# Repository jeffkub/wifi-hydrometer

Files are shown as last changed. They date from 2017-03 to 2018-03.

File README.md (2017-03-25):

# wifi-hydrometer
A WiFi-enabled hydrometer and temperature sensor using a ESP8266.  Concept taken from [iSpindel](https://github.com/universam1/iSpindel) and miniturized to fit inside a standard size soda bottle perform.
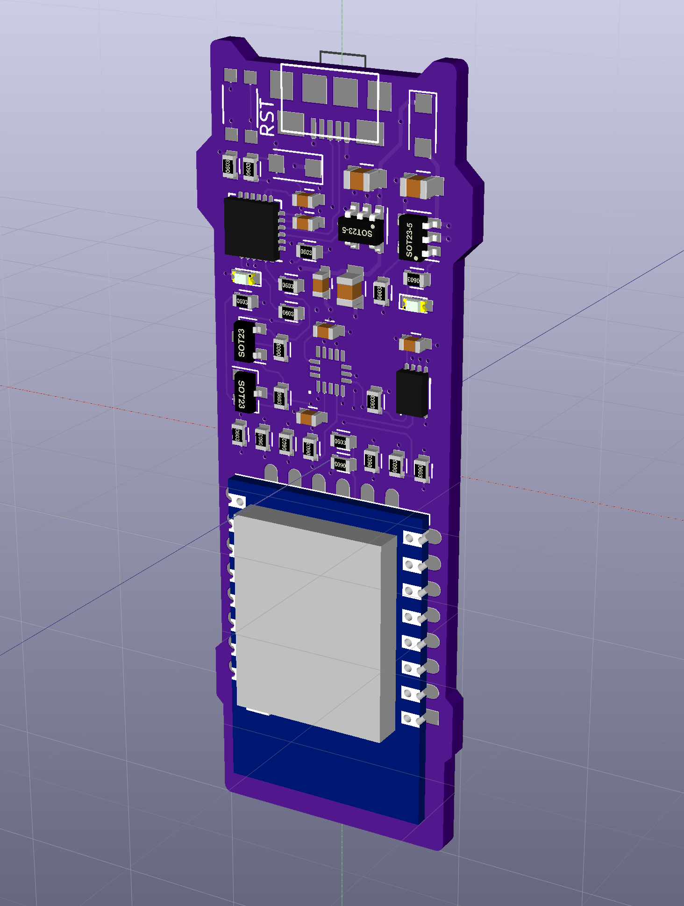
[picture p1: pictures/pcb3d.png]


# Licensing
Design is based on the Adafruit Feather ESP8266 HUZZAH.  
For more details, check out the product page at

  * https://www.adafruit.com/product/2821

Adafruit invests time and resources providing this open source design, 
please support Adafruit and open-source hardware by purchasing 
products from Adafruit!

Adapted from a design by Adafruit Industries.  
Creative Commons Attribution, Share-Alike license, check license.txt for more information
All text above must be included in any redistribution

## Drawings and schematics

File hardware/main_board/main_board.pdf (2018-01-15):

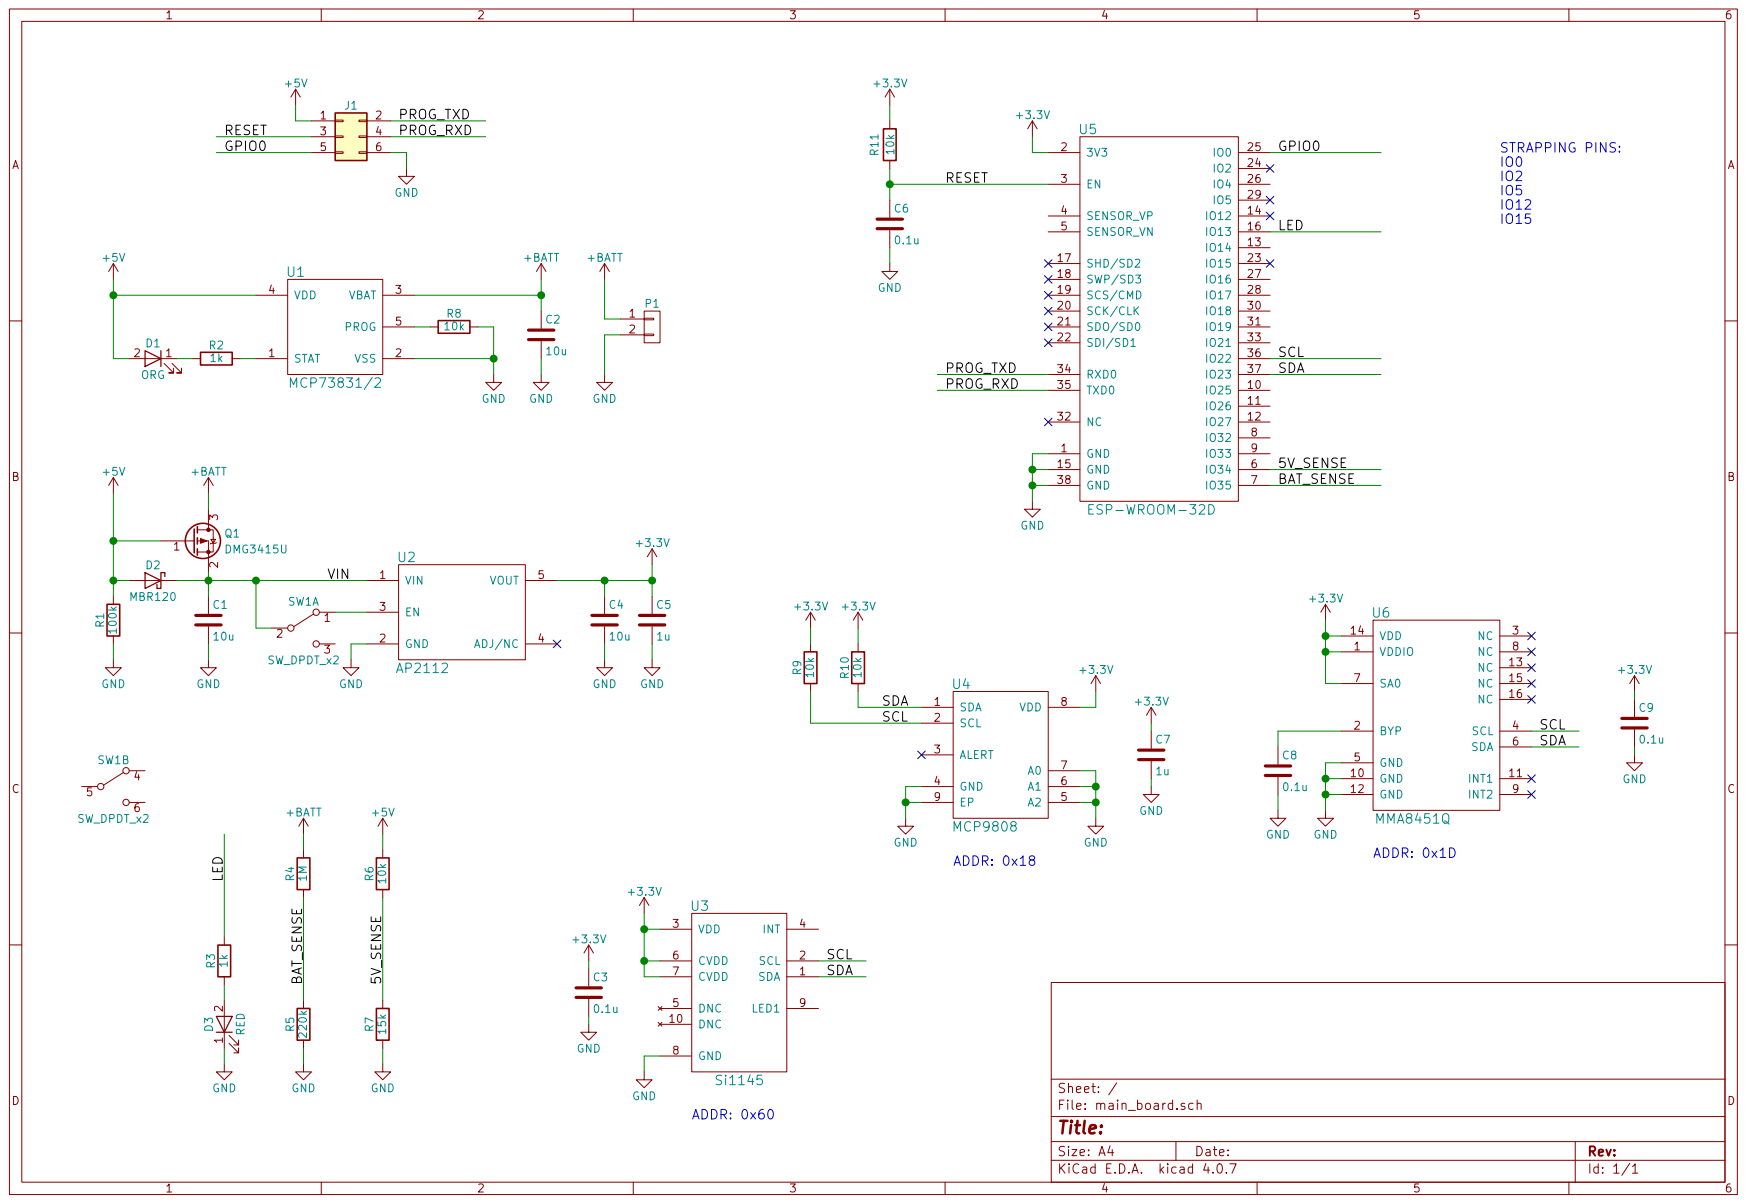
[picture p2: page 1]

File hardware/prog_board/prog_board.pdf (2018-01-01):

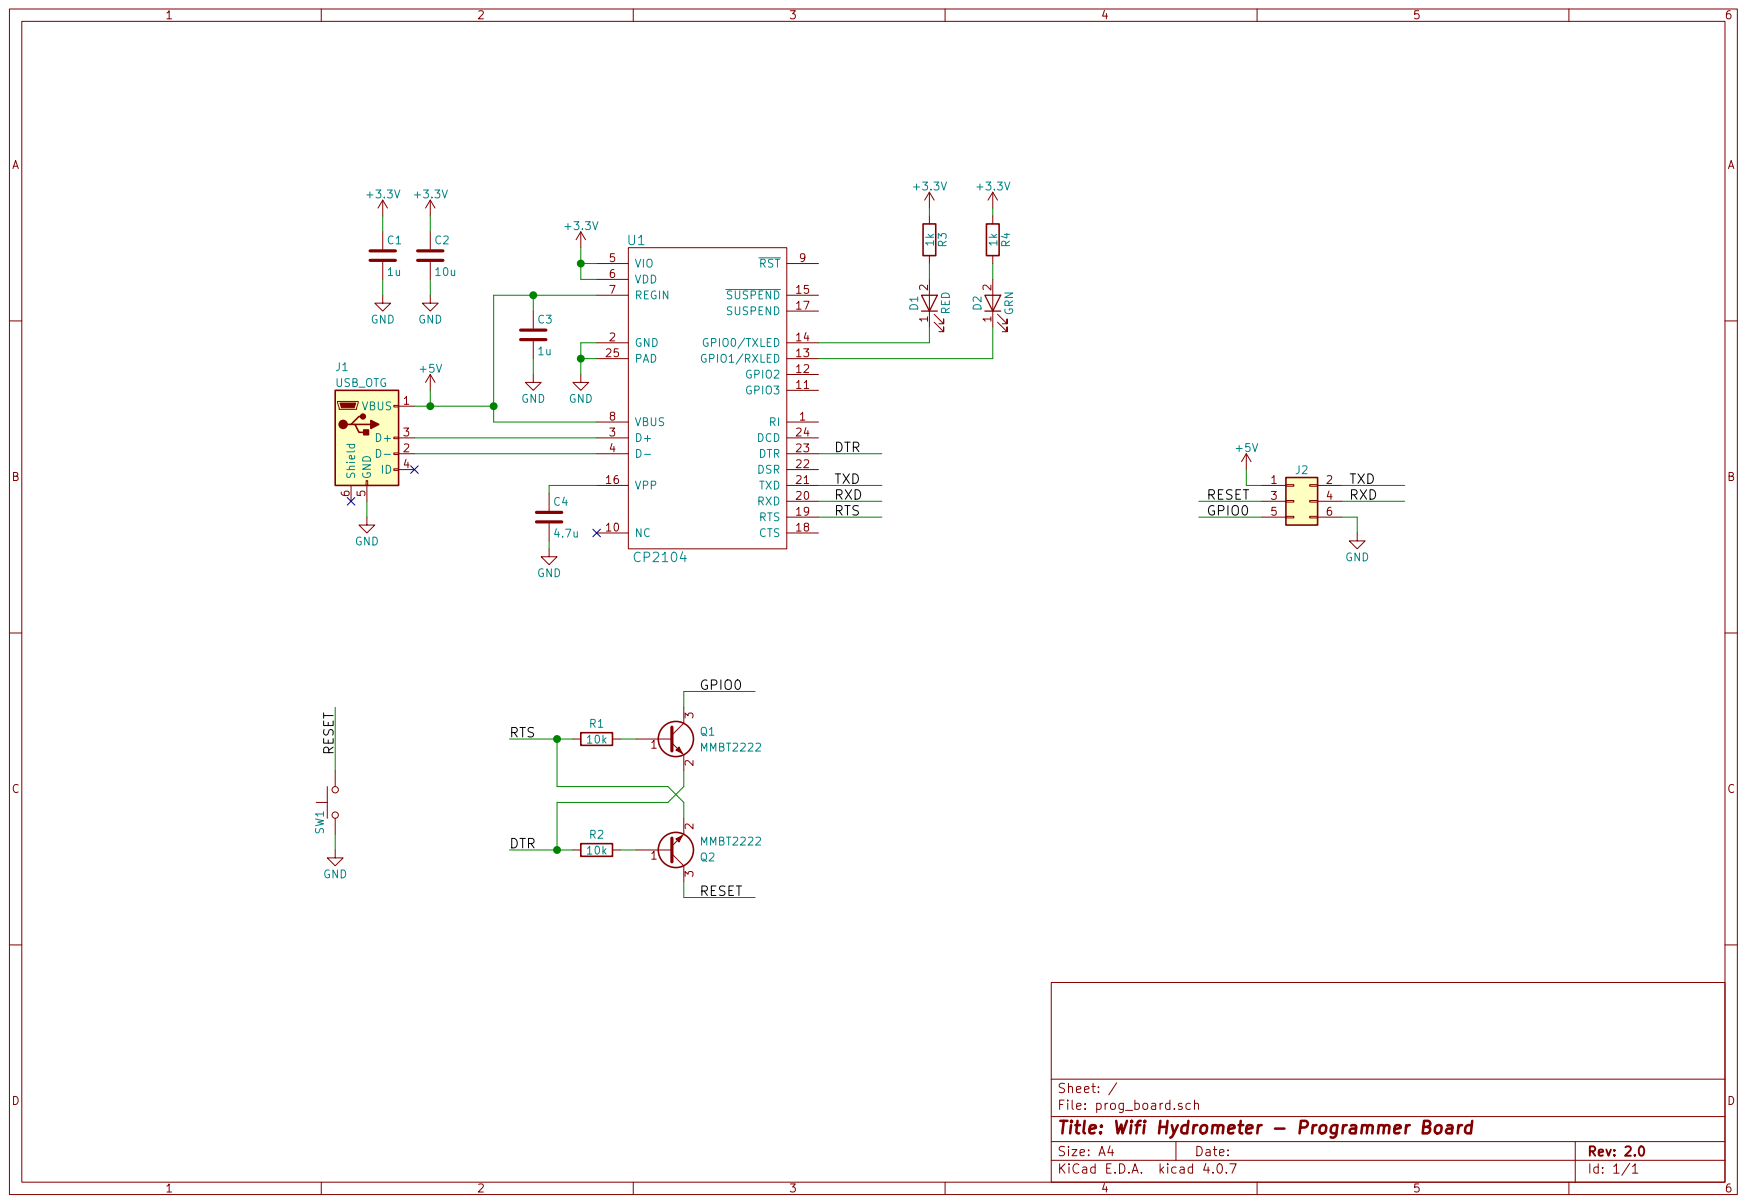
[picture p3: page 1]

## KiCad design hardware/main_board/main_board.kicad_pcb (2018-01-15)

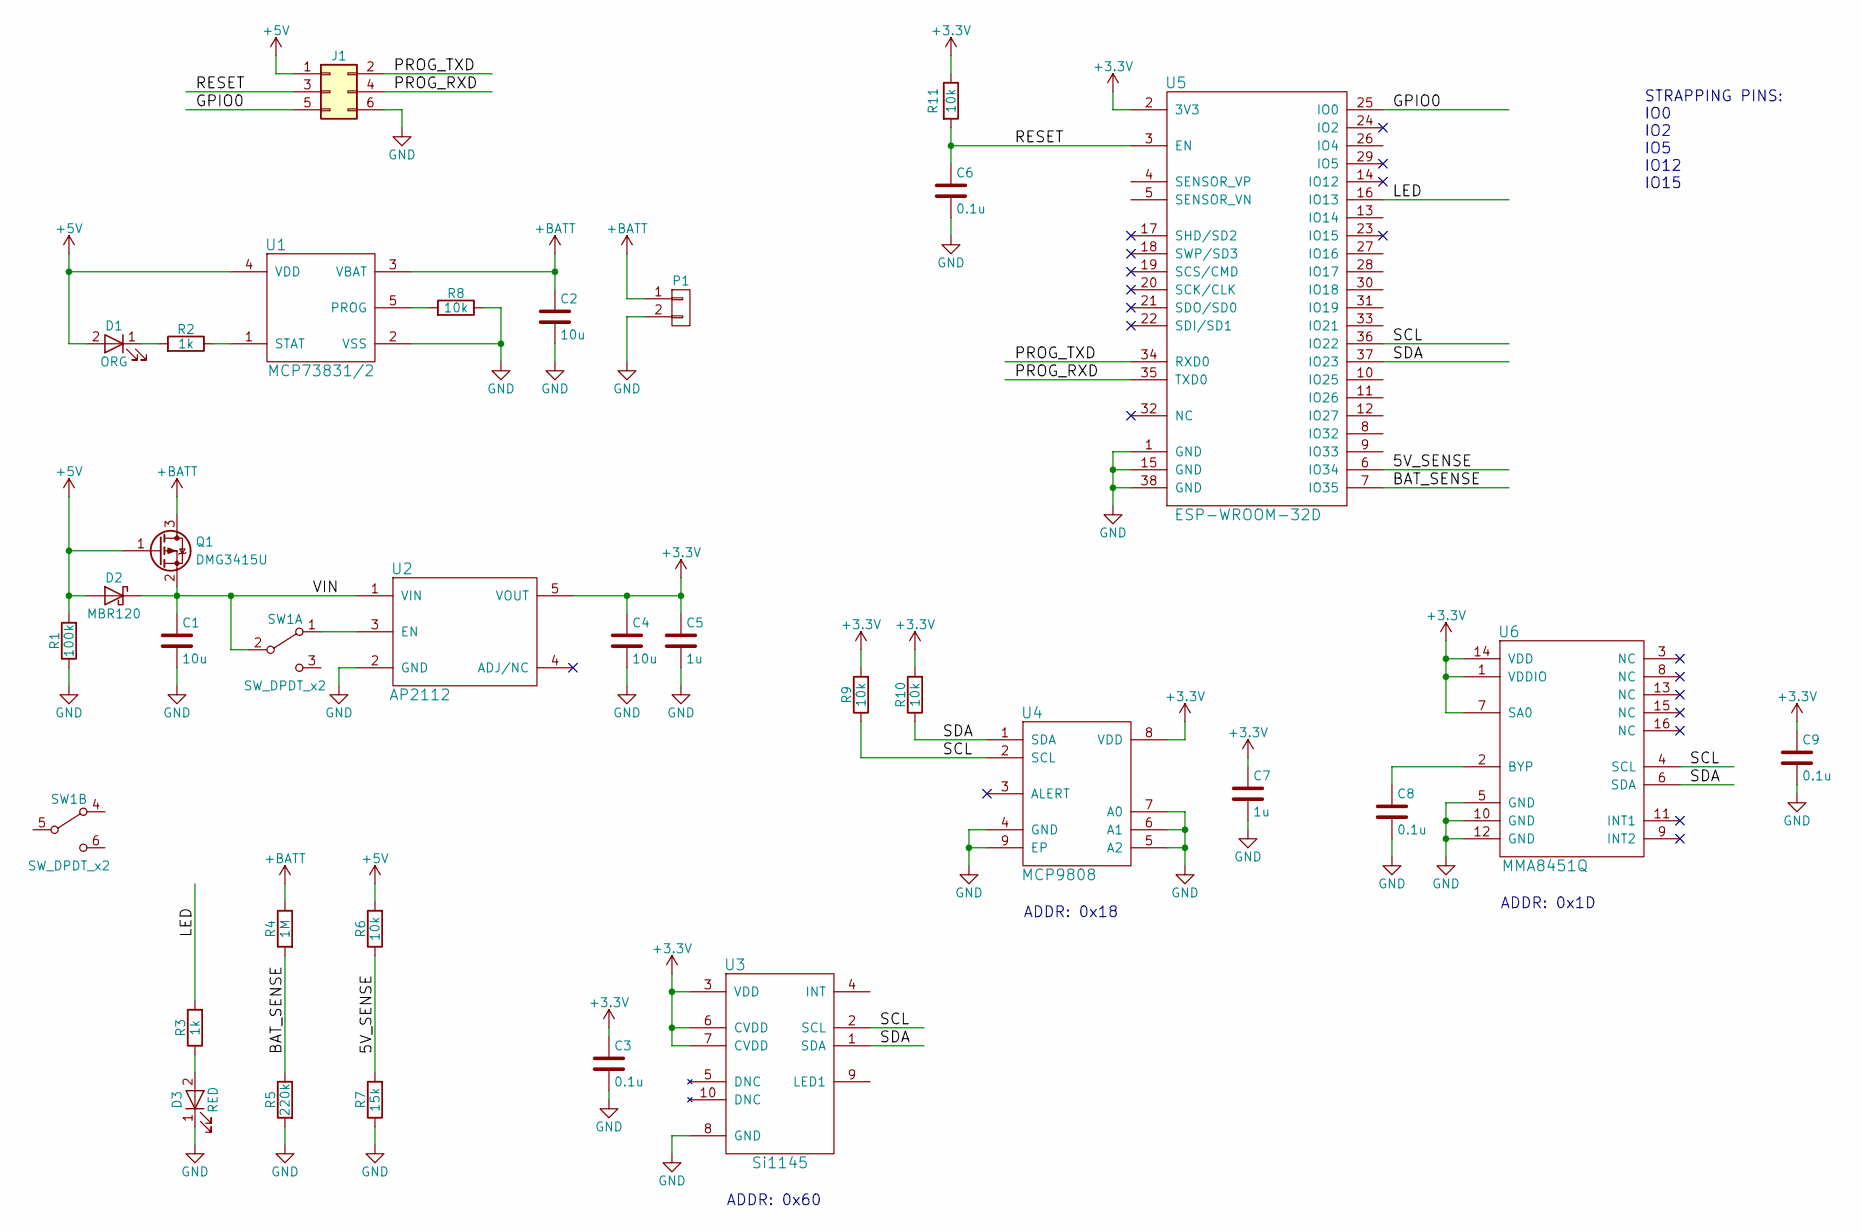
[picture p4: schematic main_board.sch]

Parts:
C1, C2, C4: 10u; C_0805; Part 311-1460-1-ND
C3, C6, C8, C9: 0.1u; C_0603; Part 311-1344-1-ND
C5, C7: 1u; C_0603; Part 311-1444-1-ND
D1: ORG; LED_0603; Part 160-1434-1-ND
D2: MBR120; SOD-123FL; Part MBR120VLSFT3GOSCT-ND
D3: RED; LED_0603; Part 160-1447-1-ND
J1: eConn_02x03_Odd_Even; Socket_Strip_Angled_2x03_Pitch2.54mm; Part S5556-ND
P1: CONN_01X02; S2B-PH-SM4-TB(LF)(SN); Part 455-1749-1-ND
Q1: DMG3415U; SOT-23; Part DMG3415UDICT-ND
R1: 100k; R_0603; Part 311-100KHRCT-ND
R2, R3: 1k; R_0603; Part 311-1.00KHRCT-ND
R4: 1M; R_0603; Part 311-1.00MHRCT-ND
R5: 220k; R_0603; Part 311-220KHRCT-ND
R6, R8, R9, R10, R11: 10k; R_0603; Part 311-10.0KHRCT-ND
R7: 15k; R_0603; Part 311-15.0KHRCT-ND
SW1: SW_DPDT_x2; CL-SB-22A; Part 563-1340-1-ND
U1: MCP73831/2; SOT-23-5; Part MCP73831T-2ACI/OTCT-ND
U2: AP2112; SOT-23-5; Part AP2112K-3.3TRG1DICT-ND
U3: Si1145; Part 336-2622-1-ND
U4: MCP9808; DFN-8-1EP_3x2mm_Pitch0.5mm; Part MCP9808T-E/MCCT-ND
U5: ESP-WROOM-32D; ESP32-WROOM; Part 1528-1801-ND
U6: MMA8451Q; Part MMA8451QR1CT-ND

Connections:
+3V3: C3.1, C4.1, C5.1, C7.1, C9.1, R9.2, R10.2, R11.1, U2.5 (VOUT), U3.3 (VDD), U3.6 (CVDD), U3.7 (CVDD), U4.8 (VDD), U5.2 (3V3), U6.1 (VDDIO), U6.7 (SA0), U6.14 (VDD)
+5V: D1.2 (A), D2.2 (A), J1.1, Q1.1 (G), R1.2, R6.2, U1.4 (VDD)
+BATT: C2.1, P1.1, Q1.3 (D), R4.1, U1.3 (VBAT)
/5V_SENSE: R6.1, R7.2, U5.6 (IO34)
/BAT_SENSE: R4.2, R5.1, U5.7 (IO35)
/GPIO0: J1.5, U5.25 (IO0)
/LED: R3.2, U5.16 (IO13)
/PROG_RXD: J1.4, U5.35 (TXD0)
/PROG_TXD: J1.2, U5.34 (RXD0)
/RESET: C6.1, J1.3, R11.2, U5.3 (EN)
/SCL: R9.1, U3.2 (SCL), U4.2 (SCL), U5.36 (IO22), U6.4 (SCL)
/SDA: R10.1, U3.1 (SDA), U4.1 (SDA), U5.37 (IO23), U6.6 (SDA)
/VIN: C1.1, D2.1 (K), Q1.2 (S), SW1.2 (B), U2.1 (VIN)
GND: C1.2, C2.2, C3.2, C4.2, C5.2, C6.2, C7.2, C8.2, C9.2, D3.1 (K), J1.6, P1.2, R1.1, R5.2, R7.1, R8.1, U1.2 (VSS), U2.2 (GND), U3.8 (GND), U4.4 (GND), U4.5 (A2), U4.6 (A1), U4.7 (A0), U4.9 (EP), U5.1 (GND), U5.15 (GND), U5.38 (GND), U6.5 (GND), U6.10 (GND), U6.12 (GND)
unnamed: C8.1, U6.2 (BYP)
unnamed: D1.1 (K), R2.2
unnamed: D3.2 (A), R3.1
unnamed: R2.1, U1.1 (STAT)
unnamed: R8.2, U1.5 (PROG)
unnamed: SW1.1 (A), U2.3 (EN)

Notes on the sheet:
STRAPPING PINS: IO0 IO2 IO5 IO12 IO15
ADDR: 0x60
ADDR: 0x1D
ADDR: 0x18

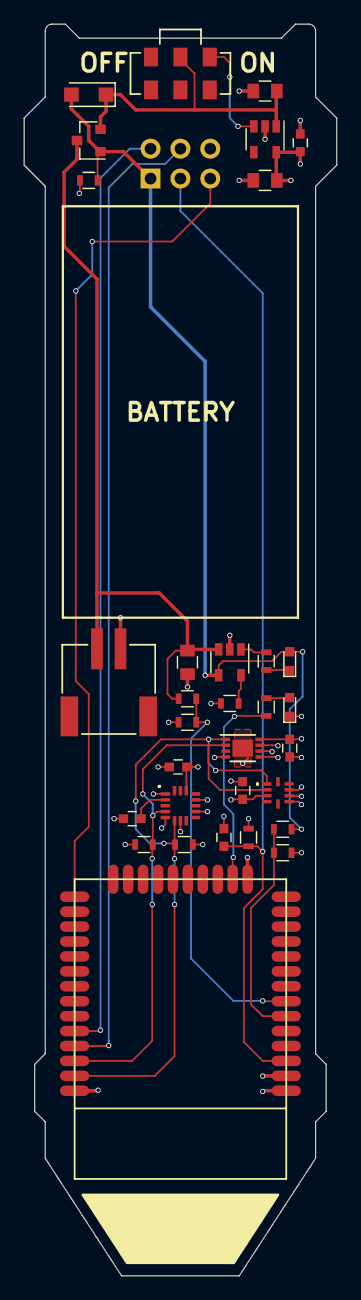
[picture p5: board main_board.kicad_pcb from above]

Board: 4 copper layers, 26.6 x 106.5 mm, 33 parts (1 on the bottom side), 20 nets.

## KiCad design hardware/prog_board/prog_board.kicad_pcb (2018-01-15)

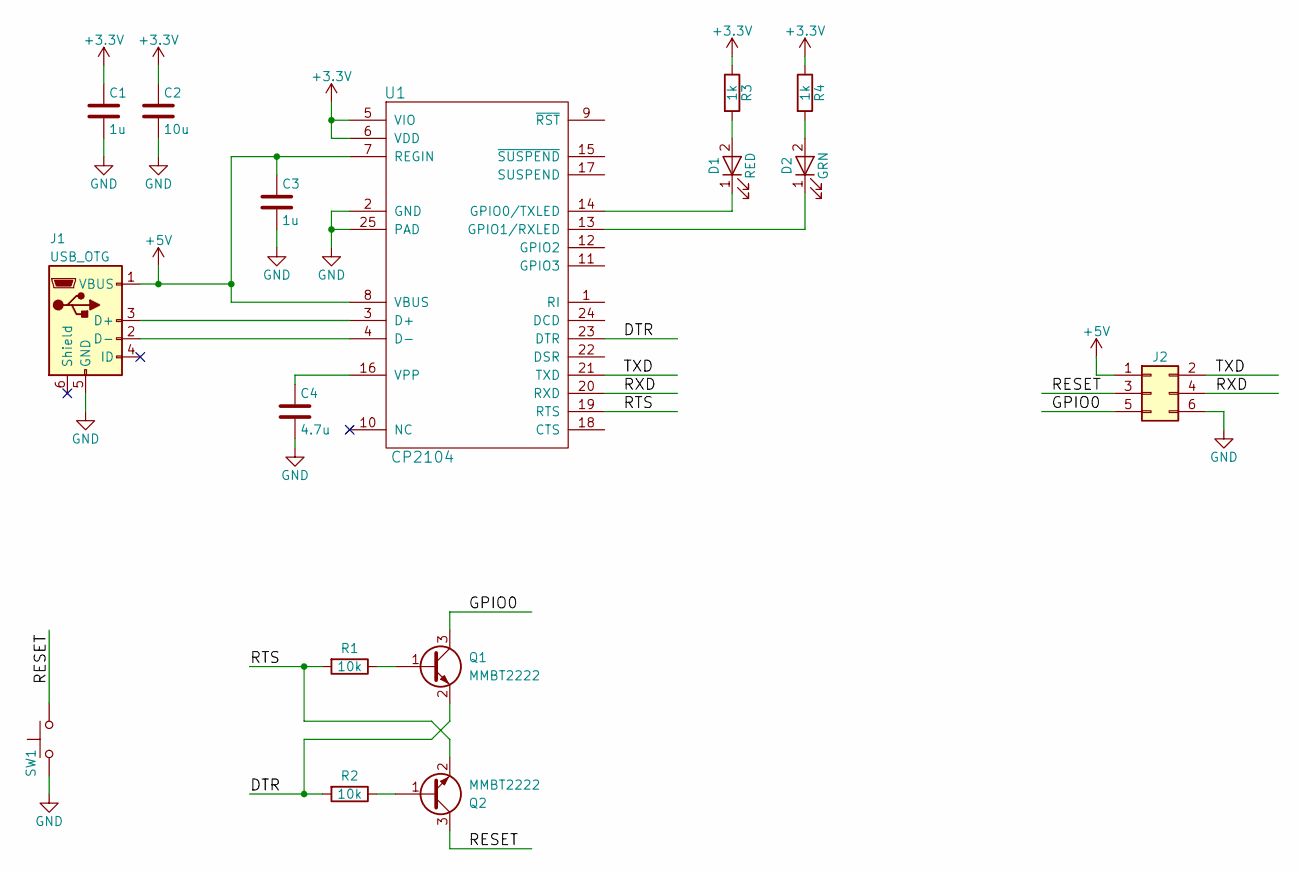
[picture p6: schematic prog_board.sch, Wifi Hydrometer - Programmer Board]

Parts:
C1, C3: 1u; C_0603; Part 311-1444-1-ND
C2: 10u; C_0805; Part 311-1460-1-ND
C4: 4.7u; C_0603; Part 311-1455-1-ND
D1: RED; LED_0603; Part 160-1447-1-ND
D2: GRN; LED_0603; Part 160-1435-1-ND
J1: USB_OTG; 10118192; Part 609-4613-1-ND
J2: Conn_02x03_Odd_Even; Pin_Header_Angled_2x03_Pitch2.54mm; Part S2111E-03-ND
Q1, Q2: MMBT2222; SOT-23; Part MMBT2222ALT1GOSCT-ND
R1, R2: 10k; R_0603; Part 311-10.0KHRCT-ND
R3, R4: 1k; R_0603; Part 311-1.00KHRCT-ND
SW1: SW_Push; KMR7; Part CKN10689CT-ND
U1: CP2104; QFN-24-1EP_4x4mm_Pitch0.5mm; Part 336-2008-5-ND

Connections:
+3V3: C1.1, C2.1, R3.1, R4.1, U1.5 (VIO), U1.6 (VDD)
+5V: C3.1, J1.1 (VBUS), J2.1, U1.7 (REGIN), U1.8 (VBUS)
/DTR: Q1.2 (E), R2.2, U1.23 (DTR)
/GPIO0: J2.5, Q1.3 (C)
/RESET: J2.3, Q2.3 (C), SW1.1
/RTS: Q2.2 (E), R1.2, U1.19 (RTS)
/RXD: J2.4, U1.20 (RXD)
/TXD: J2.2, U1.21 (TXD)
GND: C1.2, C2.2, C3.2, C4.2, J1.5 (GND), J2.6, SW1.2, U1.2 (GND), U1.25 (PAD)
unnamed: C4.1, U1.16 (VPP)
unnamed: D1.1 (K), U1.14 (GPIO0/TXLED)
unnamed: D1.2 (A), R3.2
unnamed: D2.1 (K), U1.13 (GPIO1/RXLED)
unnamed: D2.2 (A), R4.2
unnamed: J1.2 (D-), U1.4 (D-)
unnamed: J1.3 (D+), U1.3 (D+)
unnamed: Q1.1 (B), R1.1
unnamed: Q2.1 (B), R2.1

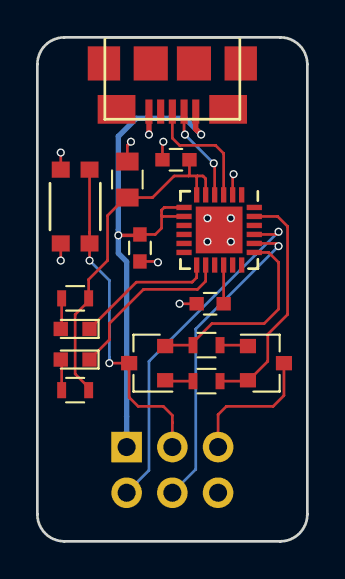
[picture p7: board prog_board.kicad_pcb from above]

Board: 2 copper layers, 15.0 x 28.0 mm, 16 parts (1 on the bottom side), 18 nets.

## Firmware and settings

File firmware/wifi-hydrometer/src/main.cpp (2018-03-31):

#include <Arduino.h>
#include <WiFi.h>
#include <Wire.h>

#include <ArduinoJson.h>
#include <MQTTClient.h>

#include "globals.h"
#include "mcp9808.h"
#include "mma8451.h"
#include "si1145.h"

static MCP9808 temp_sensor = MCP9808();
static MMA8451 accel_sensor = MMA8451();
static SI1145 light_sensor = SI1145();

static WiFiClient net;
static MQTTClient client(512);

static DynamicJsonBuffer json_buffer;

RTC_DATA_ATTR unsigned long last_run_time = 0;
RTC_DATA_ATTR unsigned int wifi_conn_fail = 0;
RTC_DATA_ATTR unsigned int mqtt_conn_fail = 0;
RTC_DATA_ATTR unsigned int sensor_init_flag = 0;

static int initSensors(void);
static int readSensors(JsonObject& data);
static void wifiEvent(system_event_id_t event, system_event_info_t info);
static int connectToWiFi(const String& ssid, const String& pass);
static int connectToServer(const String& ip, uint16_t port, const String& client_id, const String& user, const String& pass);
static int publishData(const String& topic_base, JsonObject& data);

static int initSensors(void)
{
    analogSetWidth(12);
    analogSetAttenuation(ADC_0db);
    analogSetCycles(127);

    Wire.begin(SDA_PIN, SCL_PIN);

    /* Initialize sensors on first boot only */
    if(sensor_init_flag)
    {
        return 0;
    }

    LOG("Initializing sensors\n");

    if(!temp_sensor.begin())
    {
        LOG("Failed to init MCP9808\n");
        return -1;
    }

    if(!accel_sensor.begin())
    {
        LOG("Failed to init MMA8451\n");
        return -1;
    }

    if(!light_sensor.begin())
    {
        LOG("Failed to init SI1145\n");
        return -1;
    }

    /* Mark sensors as initialized */
    sensor_init_flag = 1;

    return 0;
}

static int readSensors(JsonObject& data)
{
    float mag;

    /* Read battery voltage */
    data["bat_v"] = analogRead(BAT_SENSE_PIN) * BAT_ADC_SCALE;

    /* Read temperature sensor */
    temp_sensor.wake();
    temp_sensor.read();
    temp_sensor.shutdown();

    data["temp_f"] = temp_sensor.temp_f;

    /* Read light sensor */
    light_sensor.wake();
    light_sensor.read();
    light_sensor.shutdown();

    data["light_vis"] = light_sensor.vis;
    data["light_ir"] = light_sensor.ir;
    data["light_uv"] = light_sensor.uv;

    /* Read accelerometer sensor */
    accel_sensor.wake();
    accel_sensor.read();
    accel_sensor.shutdown();

    data["accel_x"] = accel_sensor.x_g;
    data["accel_y"] = accel_sensor.y_g;
    data["accel_z"] = accel_sensor.z_g;

    mag = sqrt(accel_sensor.x_g*accel_sensor.x_g + accel_sensor.y_g*accel_sensor.y_g + accel_sensor.z_g*accel_sensor.z_g);
    data["tilt"] = (M_PI_2 - acos(accel_sensor.y_g / mag)) * (180.0f / M_PI);

    /* Print to console */
    LOG("Sensor data:\n");
    data.prettyPrintTo(Serial);
    Serial.println("");

    return 0;
}

static void wifiEvent(system_event_id_t event, system_event_info_t info)
{
    switch(event)
    {
        case SYSTEM_EVENT_STA_START:
        {
            LOG("STA start\n");

            break;
        }
        case SYSTEM_EVENT_STA_STOP:
        {
            LOG("STA stop\n");

            break;
        }
        case SYSTEM_EVENT_STA_CONNECTED:
        {
            LOG("STA connected\n");
            LOG("  ssid     = %*s\n",
            info.connected.ssid_len, info.connected.ssid);
            LOG("  bssid    = %02X:%02X:%02X:%02X:%02X:%02X\n",
            info.connected.bssid[0], info.connected.bssid[1], info.connected.bssid[2],
            info.connected.bssid[3], info.connected.bssid[4], info.connected.bssid[5]);
            LOG("  channel  = %d\n", info.connected.channel);
            LOG("  authmode = %d\n", info.connected.authmode);

            break;
        }
        case SYSTEM_EVENT_STA_DISCONNECTED:
        {
            LOG("STA disconnected\n");
            LOG("  ssid   = %*s\n",
            info.disconnected.ssid_len, info.disconnected.ssid);
            LOG("  bssid  = %02X:%02X:%02X:%02X:%02X:%02X\n",
            info.disconnected.bssid[0], info.disconnected.bssid[1], info.disconnected.bssid[2],
            info.disconnected.bssid[3], info.disconnected.bssid[4], info.disconnected.bssid[5]);
            LOG("  reason = %d\n", info.disconnected.reason);

            break;
        }
        case SYSTEM_EVENT_STA_AUTHMODE_CHANGE:
        {
            LOG("Auth mode changed\n");
            LOG("  old_mode = %d\n", info.auth_change.old_mode);
            LOG("  new_mode = %d\n", info.auth_change.new_mode);

            break;
        }
        case SYSTEM_EVENT_STA_GOT_IP:
        {
            IPAddress ip(info.got_ip.ip_info.ip.addr);
            IPAddress netmask(info.got_ip.ip_info.netmask.addr);
            IPAddress gw(info.got_ip.ip_info.gw.addr);

            LOG("Got IP\n");
            LOG("  ip_changed = %d\n", info.got_ip.ip_changed);
            LOG("  ip_address = %s\n", ip.toString().c_str());
            LOG("  netmask    = %s\n", netmask.toString().c_str());
            LOG("  gw         = %s\n", gw.toString().c_str());

            break;
        }
        case SYSTEM_EVENT_STA_LOST_IP:
        {
            LOG("Lost IP\n");

            break;
        }
        default:
        {
            LOG("Unknown event: %d\n", event);

            break;
        }
    }

    return;
}

static int connectToWiFi(const String& ssid, const String& pass)
{
    int retry;

    WiFi.onEvent(wifiEvent);

    for(retry = 0; retry < 3; retry++)
    {
        LOG("Connecting to %s\n", ssid.c_str());

        WiFi.begin(ssid.c_str(), pass.c_str());
        if(WiFi.waitForConnectResult() == WL_CONNECTED)
        {
            return 0;
        }

        LOG("failed\n");
        wifi_conn_fail++;

        delay(5000);
    }

    return -1;
}

static int connectToServer(const String& ip, uint16_t port, const String& client_id, const String& user, const String& pass)
{
    int retry;

    for(retry = 0; retry < 3; retry++)
    {
        LOG("Connecting to MQTT server\n");

        client.begin(ip.c_str(), port, net);
        if(client.connect(client_id.c_str(), user.c_str(), pass.c_str()))
        {
            return 0;
        }

        LOG("failed. lastError = %d\n", client.lastError());
        mqtt_conn_fail++;

        delay(5000);
    }

    return -1;
}

static int publishData(const String& topic_base, JsonObject& data)
{
    String payload;

    data["wifi_conn_fail"] = wifi_conn_fail;
    data["mqtt_conn_fail"] = mqtt_conn_fail;
    data["last_run_time"]  = (float)last_run_time / 1000000.0f;

    data.printTo(payload);

    LOG("Publishing sensor data\n");
    LOG("  topic_base: %s\n", topic_base.c_str());
    LOG("  payload:    %s\n", payload.c_str());

    if(!client.publish(topic_base + "/json", payload, false, LWMQTT_QOS2))
    {
        LOG("failed. lastError = %d\n", client.lastError());
        return -1;
    }

    if(!client.publish(topic_base + "/bat_v", data["bat_v"], true, LWMQTT_QOS1))
    {
        LOG("failed. lastError = %d\n", client.lastError());
        return -1;
    }

    if(!client.publish(topic_base + "/tilt", data["tilt"], true, LWMQTT_QOS1))
    {
        LOG("failed. lastError = %d\n", client.lastError());
        return -1;
    }

    wifi_conn_fail = 0;
    mqtt_conn_fail = 0;

    return 0;
}

void setup()
{
    JsonObject& sensor_data = json_buffer.createObject();

    Serial.begin(115200);
    LOG("Program start\n");

    ledcAttachPin(LED_PIN, LED_CH);
    ledcSetup(LED_CH, 12000, 8);

    if(initSensors())
    {
        goto sleep;
    }

    if(readSensors(sensor_data))
    {
        goto sleep;
    }

    ledcWrite(LED_CH, 16);

    if(connectToWiFi(WIFI_SSID, WIFI_PASS))
    {
        goto sleep;
    }

    if(connectToServer(MQTT_SERVER, MQTT_PORT, WiFi.macAddress(), MQTT_USER, MQTT_PASS))
    {
        goto sleep;
    }

    publishData(MQTT_TOPIC_BASE, sensor_data);

sleep:
    LOG("Disconnecting\n");
    client.disconnect();
    delay(2000);
    WiFi.disconnect(true);
    delay(2000);

    ledcWrite(LED_CH, 0);

    LOG("Going to sleep\n");
    esp_sleep_enable_timer_wakeup(TIME_TO_SLEEP_US);
    last_run_time = micros();
    esp_deep_sleep_start();

    return;
}

void loop()
{
    return;
}

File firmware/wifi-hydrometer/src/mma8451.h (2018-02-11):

#ifndef _mma8451_h_
#define _mma8451_h_

#include <Arduino.h>

#include "sensor.h"

#define MMA8451_DEFAULT_ADDRESS         0x1D

#define MMA8451_OUT_X_MSB               0x01
#define MMA8451_SYSMOD                  0x0B
#define MMA8451_WHOAMI                  0x0D
#define MMA8451_XYZ_DATA_CFG            0x0E
#define MMA8451_PL_STATUS               0x10
#define MMA8451_PL_CFG                  0x11
#define MMA8451_CTRL_REG1               0x2A
#define MMA8451_CTRL_REG2               0x2B
#define MMA8451_CTRL_REG4               0x2D
#define MMA8451_CTRL_REG5               0x2E

#define MMA8451_WHOAMI_DEVID            0x1A

#define MMA8451_XYZ_DATA_CFG_FS(x)      (x << 0)
#define MMA8451_XYZ_DATA_CFG_HPF_OUT    (1 << 4)

#define MMA8451_CTRL_REG1_ACTIVE        (1 << 0)
#define MMA8451_CTRL_REG1_F_READ        (1 << 1)
#define MMA8451_CTRL_REG1_LNOISE        (1 << 2)
#define MMA8451_CTRL_REG1_DR(x)         (x << 3)
#define MMA8451_CTRL_REG1_ASLP_RATE(x)  (x << 6)

#define MMA8451_CTRL_REG2_MODS(x)       (x << 0)
#define MMA8451_CTRL_REG2_SLPE          (1 << 2)
#define MMA8451_CTRL_REG2_SMODS(x)      (x << 3)
#define MMA8451_CTRL_REG2_RST           (1 << 6)
#define MMA8451_CTRL_REG2_ST            (1 << 7)

typedef enum
{
    MMA8451_RANGE_2_G   = 0b00,
    MMA8451_RANGE_4_G   = 0b01,
    MMA8451_RANGE_8_G   = 0b10,

    MMA8451_RANGE_MASK  = 0b11
} mma8451_range_t;

typedef enum
{
    MMA8451_DATARATE_800_HZ     = 0b000,
    MMA8451_DATARATE_400_HZ     = 0b001,
    MMA8451_DATARATE_200_HZ     = 0b010,
    MMA8451_DATARATE_100_HZ     = 0b011,
    MMA8451_DATARATE_50_HZ      = 0b100,
    MMA8451_DATARATE_12_5_HZ    = 0b101,
    MMA8451_DATARATE_6_25HZ     = 0b110,
    MMA8451_DATARATE_1_56_HZ    = 0b111,

    MMA8451_DATARATE_MASK       = 0b111
} mma8451_dataRate_t;

typedef enum
{
    MMA8451_MODS_NORMAL                 = 0b00,
    MMA8451_MODS_LOW_NOISE_LOW_POWER    = 0b01,
    MMA8451_MODS_HIGH_RESOLUTION        = 0b10,
    MMA8451_MODS_LOW_POWER              = 0b11,

    MMA8451_MODS_MASK                   = 0b11
} mma8451_mods_t;

class MMA8451 : public Sensor
{
public:
    MMA8451(uint8_t addr = MMA8451_DEFAULT_ADDRESS);

    virtual bool begin(void);

    virtual void wake(void);
    virtual void shutdown(void);

    virtual void read(void);

    /* Last sensor readings */
    float x_g;
    float y_g;
    float z_g;

private:
    void write8(uint8_t reg, uint8_t value);
    uint8_t read8(uint8_t reg);

    uint8_t _i2caddr;
};

#endif /* #ifndef _mma8451_h_ */

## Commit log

2017-03-25 Moved config into header file. Updated PCB image
2017-12-30 Separating design into main and programmer boards
    [main_board.kicad_pcb, main_board.sch, prog_board.kicad_pcb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]
2017-12-30 Moved components to programmer board
    [main_board.sch, prog_board.sch]
2017-12-30 Working on schematic
    [main_board.sch, prog_board.sch]
2017-12-30 Working on layout
    [main_board.kicad_pcb, main_board.sch, prog_board.kicad_pcb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]
2017-12-31 Changed board size to use with new tubes
    [main_board.kicad_pcb, prog_board.kicad_pcb]
2018-01-01 Finished routing programming board
    [prog_board.kicad_pcb]
2018-01-12 Updated PCB board outline for new tube
    [main_board.kicad_pcb]
2018-01-13 Working on component placement
    [main_board.kicad_pcb, main_board.sch]
2018-01-13 Added UV sensor. Working on layout
    [main_board.kicad_pcb, main_board.sch]
2018-01-14 Finished routing board
    [main_board.kicad_pcb, main_board.sch]
2018-01-15 Minor changes to BOM
    [main_board.kicad_pcb, main_board.sch, prog_board.kicad_pcb]
2018-02-05 Switched to PlatformIO
2018-02-06 Switched MQTT library
2018-02-09 Create driver class for MMA8451 with ability to go into suspend/active modes
2018-02-10 Cleaned up mma8451 driver code
2018-02-10 Created driver class for temperature sensor
2018-02-11 Implemented MCP9808 temp sensor driver
2018-02-11 Created a Sensor base class. Working on SI1145 light sensor driver
2018-02-12 Working on SI1145 light sensor driver
2018-02-13 WWorking on SI1145 light sensor driver
2018-02-13 Sensors are now initialized on first boot only
2018-03-31 Switched to mqtt server on raspberry pi
2018-03-31 Switched to daemonize library
2018-04-03 Showing all log entries for a device
2018-04-05 Implemented index and device page
2018-04-09 Added battery voltage chart
